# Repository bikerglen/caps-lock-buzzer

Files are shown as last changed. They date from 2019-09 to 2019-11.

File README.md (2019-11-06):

# The Annoying CAPS LOCk Buzzer

More information is available on my personal blog:

First Version (as shown in the Keysight Labs video):

https://bikerglen.com/blog/the-annoying-caps-lock-warning-buzzer/

Second version with some minor updates:

https://bikerglen.com/blog/updates-to-the-annoying-caps-lock-warning-buzzer/

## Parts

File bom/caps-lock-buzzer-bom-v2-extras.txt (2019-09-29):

For the v2 version of this board with ESD protection, button, and LED, the following additonal parts are needed:

	Mouser #	Mfr. #	Manufacturer	Customer #	Description	RoHS	Lifecycle	Order Qty.	Price (USD)	Ext.: (USD)
1	611-KMR211NGLFS	KMR211NGLFS	C&K Switches		Tactile Switches Tact	RoHS Compliant		2	$0.52	$1.04
2	771-PRTR5V0U2X-T/R	PRTR5V0U2X,215	Nexperia		ESD Suppressors / TVS Diodes 5.5V DUAL R-R ESD ULTRA LOW CAP	RoHS Compliant		2	$0.51	$1.02
3	645-599-0130-007F	599-0130-007F	Dialight		Standard LEDs - SMD SMD 0805 ORANGE	RoHS Compliant	New Product	10	$0.264	$2.64

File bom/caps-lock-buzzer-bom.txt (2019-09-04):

	Mouser #	Mfr. #	Manufacturer	Customer #	Description	RoHS	Lifecycle	Order Qty.	Price (USD)	Ext.: (USD)
1	80-C1206C474K5R	C1206C474K5RACTU	KEMET		Multilayer Ceramic Capacitors MLCC - SMD/SMT 50V 0.47uF X7R 1206 10%	RoHS Compliant		1	$0.23	$0.23
2	80-C1210C105K4P	C1210C105K4PACTU	KEMET		Multilayer Ceramic Capacitors MLCC - SMD/SMT 16V 1uF X5R 1210 10%	RoHS Compliant		1	$1.26	$1.26
3	80-C1206C104J4R	C1206C104J4RACTU	KEMET		Multilayer Ceramic Capacitors MLCC - SMD/SMT 16V 0.1uF X7R 1206 5%	RoHS Compliant		1	$0.56	$0.56
4	710-629105136821	629105136821	Wurth Elektronik		USB Connectors WR-COM Type B SMT 5Pin Horztl FmlMicro	RoHS Compliant		1	$1.21	$1.21
5	579-PIC16F1459-I/SS	PIC16F1459-I/SS	Microchip		8-bit Microcontrollers - MCU 14KB Fl 1kB R 48MHz Int. Oc 18 I0	RoHS Compliant		1	$1.66	$1.66
6	621-1N4148W-F	1N4148W-7-F	Diodes Incorporated		Diodes - General Purpose, Power, Switching SURFACE MOUNT FAST SWITCHING DIODE	RoHS Compliant		1	$0.16	$0.16
7	522-FMMT619TA	FMMT619TA	Diodes Incorporated		Bipolar Transistors - BJT NPN SuperSOT	RoHS Compliant		1	$0.55	$0.55
8	652-CR0805JW-102ELF	CR0805-JW-102ELF	Bourns		Thick Film Resistors - SMD 1K 5%	RoHS Compliant By Exemption		1	$0.10	$0.10
9	490-CX-0905C	CX-0905C	CUI Inc.		Audio Indicators & Alerts Buzzers	RoHS Compliant		1	$2.43	$2.43

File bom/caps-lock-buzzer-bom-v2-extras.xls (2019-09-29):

SHOPPING CART
This is not an invoice
28-Sep-19 22:17:19
 | Mouser # | Mfr. # | Manufacturer | Customer # | Description | RoHS | Lifecycle | Order Qty. | Price (USD) | Ext.: (USD)
1 | 611-KMR211NGLFS | KMR211NGLFS | C&K Switches |  | Tactile Switches Tact | RoHS Compliant |  | 2 | $0.52 | $1.04
2 | 771-PRTR5V0U2X-T/R | PRTR5V0U2X,215 | Nexperia |  | ESD Suppressors / TVS Diodes 5.5V DUAL R-R ESD ULTRA LOW CAP | RoHS Compliant |  | 2 | $0.51 | $1.02
3 | 645-599-0130-007F | 599-0130-007F | Dialight |  | Standard LEDs - SMD SMD 0805 ORANGE | RoHS Compliant | New Product | 10 | $0.264 | $2.64
By submitting your order you agree to these terms and conditions. (https://www.mouser.com/saleterms) |  |  |  |  |  |  |  |  | Merchandise Total: | $4.70
Prices are reflected at the date and time shown. |  |  |  |  |  |  |  |  | Shipping Charge: | $7.99

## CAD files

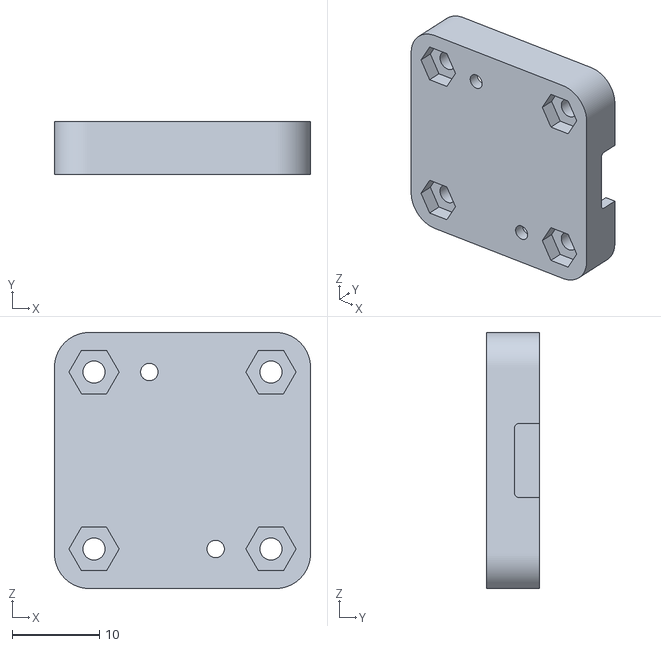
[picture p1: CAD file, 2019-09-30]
enclosure/v2/caps-lock-buzzer-v2-bottom.stl
29.4 x 6.05 x 29.4

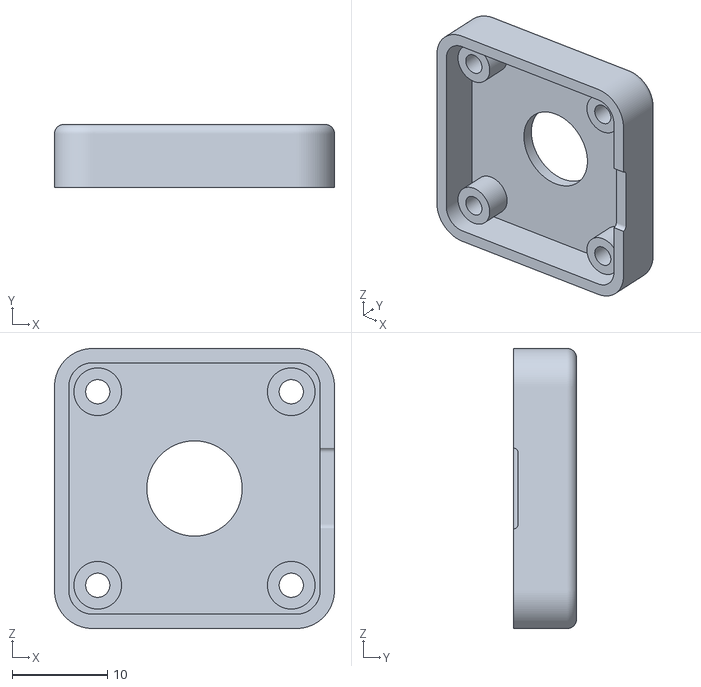
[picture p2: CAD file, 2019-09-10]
enclosure/v2/caps-lock-buzzer-v2-top.stl
29.4 x 6.65 x 29.4

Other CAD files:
software/caps-lock-buzzer-pic16f1459-nobtld.X/dist/LPCUSBDK_16F1459/production/caps-lock-buzzer-pic16f1459-nobtld.X.production.obj
enclosure/v1/caps-lock-buzzer-bottom.stl
enclosure/v1/caps-lock-buzzer.f3z
enclosure/v2/caps-lock-buzzer-v2-v5.f3z

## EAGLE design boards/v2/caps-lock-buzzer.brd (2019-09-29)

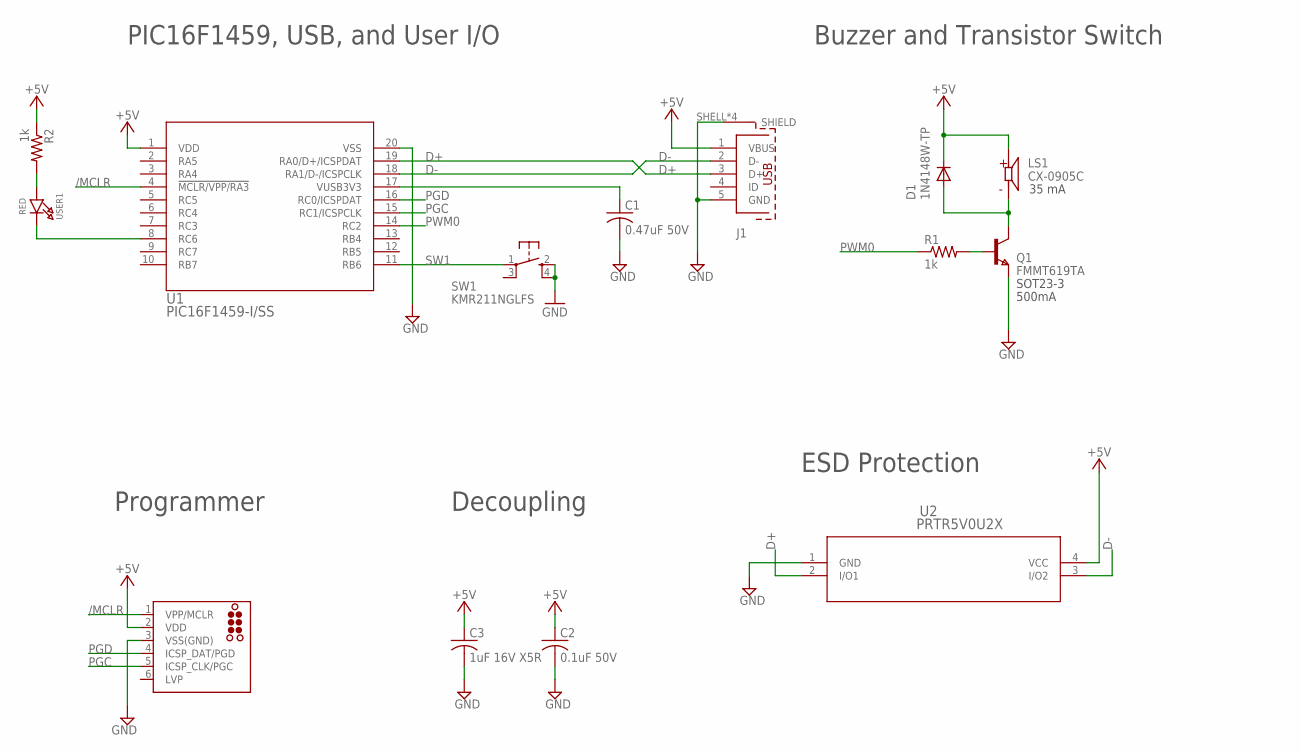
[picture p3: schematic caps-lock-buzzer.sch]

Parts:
C1: 0.47uF 50V; C1206K; MFR_PART_NO C1206C474K5RACTU
C2: 0.1uF 50V; C1206K; MFR_PART_NO C1206S104M5RACTU
C3: 1uF 16V X5R; C1210; MFR_PART_NO C1210C105K4PACTU
D1: 1N4148W-TP; SOD123
J1: 629105136821
J3: TC2030-MCP-NL
LS1: CX-0905C; CUI_CX-0905C
Q1: FMMT619TA; SOT-23
R1, R2: 1k; R0805
SW1: KMR211NGLFS; KMR2
U1: PIC16F1459-I/SS; SSOP20_MC
U2: PRTR5V0U2X; SOT143B
USER1: RED; CHIPLED_0805_NOOUTLINE

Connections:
+5V: C2.1, C3.1, D1.C, J1.1 (VBUS), J3.2 (VDD), LS1.P, R2.1, U1.1 (VDD), U2.4 (VCC)
/MCLR: J3.1 (VPP/MCLR), U1.4 (!MCLR/VPP/RA3)
D+: J1.3 (D+), U1.19 (RA0/D+/ICSPDAT), U2.2 (I/O1)
D-: J1.2 (D-), U1.18 (RA1/D-/ICSPCLK), U2.3 (I/O2)
GND: C1.2, C2.2, C3.2, J1.5 (GND), J1.SHELL (SHIELD), J1.SHELL1 (SHIELD), J1.SHELL2 (SHIELD), J1.SHELL3 (SHIELD), J3.3 (VSS(GND)), Q1.2 (E), SW1.2 (S), SW1.4 (S1), U1.20 (VSS), U2.1 (GND)
unnamed: R2.2, USER1.A
unnamed: U1.8 (RC6), USER1.C
unnamed: Q1.3 (B), R1.2
OUT0: D1.A, LS1.N, Q1.1 (C)
PGC: J3.5 (ICSP_CLK/PGC), U1.15 (RC1/ICSPCLK)
PGD: J3.4 (ICSP_DAT/PGD), U1.16 (RC0/ICSPDAT)
PWM0: R1.1, U1.14 (RC2)
SW1: SW1.1, U1.11 (RB6)
VUSB: C1.1, U1.17 (VUSB3V3)

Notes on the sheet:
SOT23-3
500mA
PIC16F1459, USB, and User I/O
Buzzer and Transistor Switch
Programmer
Decoupling
35 mA
ESD Protection

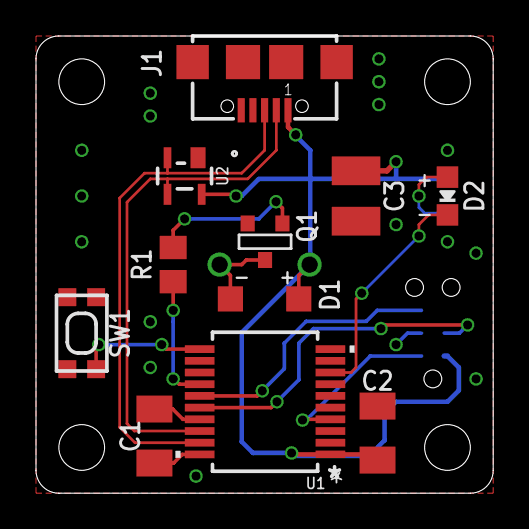
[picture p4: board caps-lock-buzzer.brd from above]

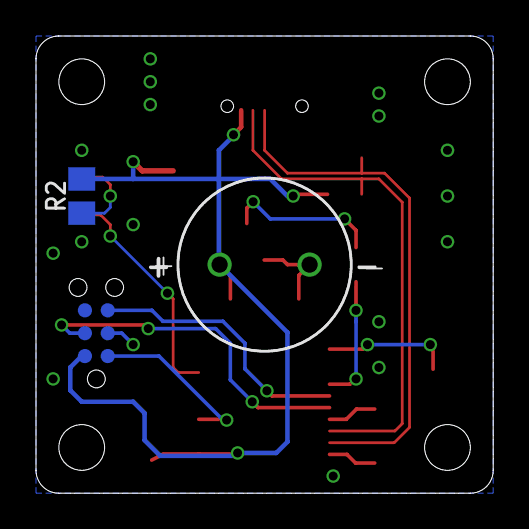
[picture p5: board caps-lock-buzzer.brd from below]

Board: 2 copper layers, 25.4 x 25.4 mm, 14 parts (3 on the bottom side), 14 nets.

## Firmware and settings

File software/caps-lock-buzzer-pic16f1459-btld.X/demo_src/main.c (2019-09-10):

/*******************************************************************************
Copyright 2016 Microchip Technology Inc. (www.microchip.com)

Licensed under the Apache License, Version 2.0 (the "License");
you may not use this file except in compliance with the License.
You may obtain a copy of the License at

    http://www.apache.org/licenses/LICENSE-2.0

Unless required by applicable law or agreed to in writing, software
distributed under the License is distributed on an "AS IS" BASIS,
WITHOUT WARRANTIES OR CONDITIONS OF ANY KIND, either express or implied.
See the License for the specific language governing permissions and
limitations under the License.

To request to license the code under the MLA license (www.microchip.com/mla_license), 
please contact mla_licensing@microchip.com
*******************************************************************************/

// *****************************************************************************
// *****************************************************************************
// Section: Included Files
// *****************************************************************************
// *****************************************************************************
/* Standard C includes */
#include <stdint.h>

/* Microchip library includes */
#include "system.h"

#include "usb.h"
#include "usb_device_hid.h"

/* Demo project includes */
#include "app_led_usb_status.h"
#include "app_device_keyboard.h"

int main(void)
{
    SYSTEM_Initialize( SYSTEM_STATE_USB_START );

    USBDeviceInit();
    USBDeviceAttach();

    while(1)
    {
        SYSTEM_Tasks();

        #if defined(USB_POLLING)
        /* Check bus status and service USB interrupts.  Interrupt or polling
         * method.  If using polling, must call this function periodically.
         * This function will take care of processing and responding to SETUP
         * transactions (such as during the enumeration process when you first
         * plug in).  USB hosts require that USB devices should accept and
         * process SETUP packets in a timely fashion.  Therefore, when using
         * polling, this function should be called regularly (such as once every
         * 1.8ms or faster** [see inline code comments in usb_device.c for
         * explanation when "or faster" applies])  In most cases, the
         * USBDeviceTasks() function does not take very long to execute
         * (ex: <100 instruction cycles) before it returns. */
        USBDeviceTasks();
        #endif

        /* Run the keyboard demo tasks. */
        APP_KeyboardTasks();
    }//end while
}//end main

/*******************************************************************************
 End of File
*/

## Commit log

2019-09-10 added boards, enclosure, and software
    [caps-lock-buzzer-bottom.stl, caps-lock-buzzer-pic16f1459-nobtld.X.production.obj, caps-lock-buzzer-top.stl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]
2019-09-14 Cleaned up for video
    [caps-lock-buzzer.sch]
2019-09-29 Added v2 boards with ESD, button, and LED.
    [caps-lock-buzzer.brd, caps-lock-buzzer.sch]
2019-09-29 Fixed LED resistor value.
    [caps-lock-buzzer.brd, caps-lock-buzzer.sch]
2019-09-29 Added BOMs with extra parts needed for v2 version of board.
    [caps-lock-buzzer-bom-v2-extras.xls, caps-lock-buzzer-bom.xls]
2019-09-30 added v2 stl for enclosure
    [caps-lock-buzzer-v2-bottom.stl, caps-lock-buzzer-v2-top.stl]
2019-09-30 added Fusion 360 archive of enclosure
    [caps-lock-buzzer-v2-v5.f3z]

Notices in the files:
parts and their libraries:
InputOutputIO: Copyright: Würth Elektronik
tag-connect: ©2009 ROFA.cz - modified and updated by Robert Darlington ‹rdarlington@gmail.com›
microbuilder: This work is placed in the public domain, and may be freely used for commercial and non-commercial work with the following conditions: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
